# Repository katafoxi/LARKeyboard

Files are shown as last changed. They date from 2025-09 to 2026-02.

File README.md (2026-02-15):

# LARKeyboard

Кастомная механическая клавиатура с открытым исходным кодом и интегрированным трекболом.

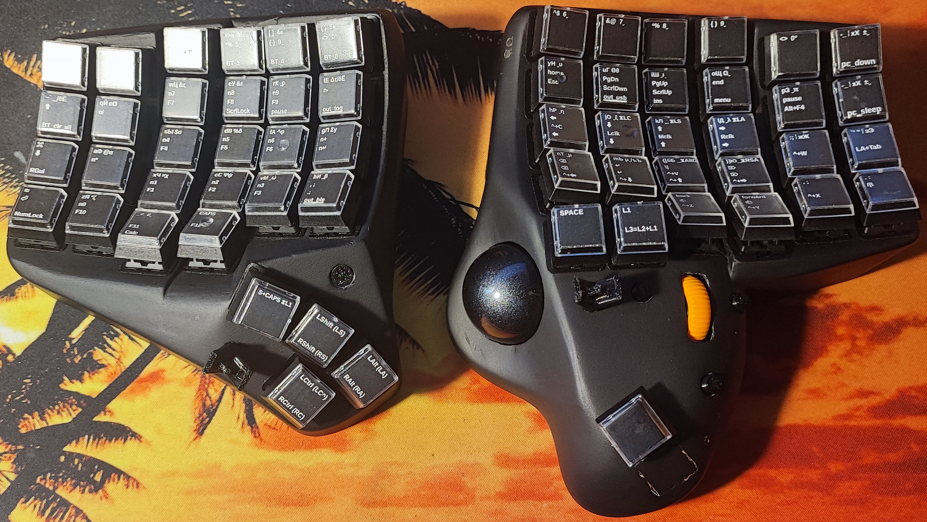
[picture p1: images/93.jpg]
LARKeyboard — вид спереди
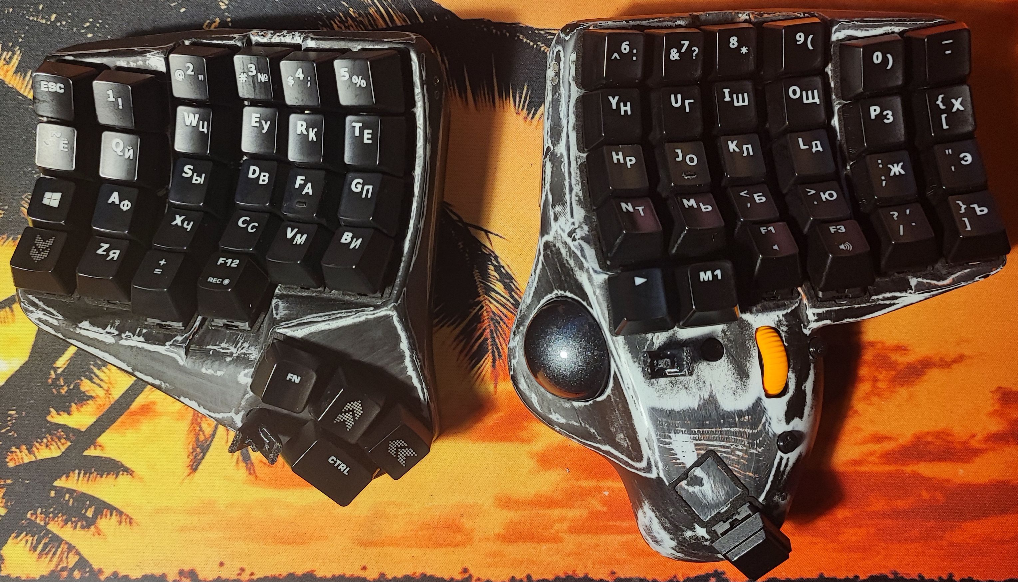
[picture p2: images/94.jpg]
LARKeyboard — вид сбоку
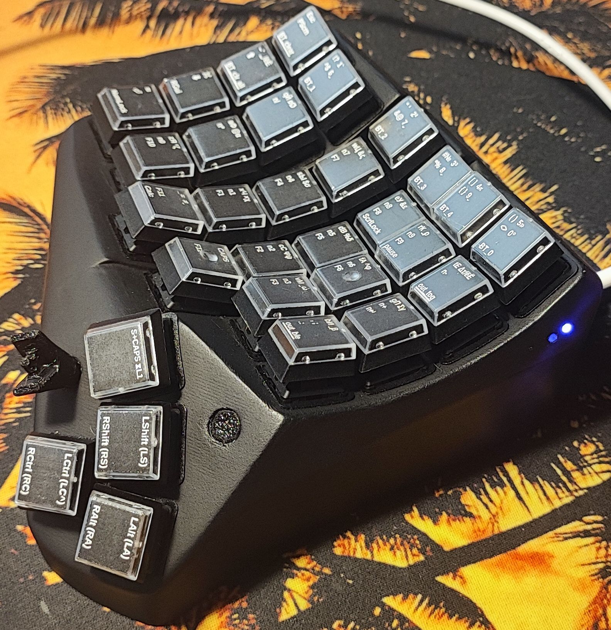
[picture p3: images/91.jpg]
LARKeyboard — трекбол и thumb cluster
  

---

## 📑 Содержание

- [Характеристики](#характеристики)
- [Быстрые ссылки](#-быстрые-ссылки)
- [Hardware](#-hardware) — BOM, инструменты, модели, этапы сборки
- [Дополнительная информация](#-дополнительная-информация) — прошивка и ссылки

---

## Характеристики  
- **Прошивка:** ZMK 
- **Макет:** Split Dactyl Manuform
- **Микроконтроллер:** (NRF52840 Development Board )  
- **Кейкапы:** ( MX )  
- **Интерфейс:** (USB-C, Bluetooth)  
- **Особенности:** 
  - длительное время автономной работы, благодаря 4 акумуляторам формата AA и возможности использования донгла
  - интегрированный серийный трекбол ProtoArc EM04 Wireless, функционирующий независимо от клавиатуры
  - 9 клавиш на thumbcluster
  - сборка без плат
  - подходит для больших и маленьких рук

## 🔗 Быстрые ссылки
- [Большая статья](https://habr.com/ru/articles/946684/)

- 📁 [Репозиторий с прошивкой](https://github.com/katafoxi/zmk-keyboard-lark)

- 📊 [Легенды клавиш и кеймап](https://docs.google.com/spreadsheets/d/1xXg7V_umpOhjsuPLZJ3ickMg2kA1LSvM3Gqmz-Sg8EQ/edit)

## 🛠️ Hardware
<details>
<summary>📦 Bill of Materials (BOM) (кликните, чтобы развернуть)</summary>

| Этап сборки | Компонент | Количество |
| --- | :--- | ---: |
| 3D-печать | Филамент для 3D-печати | 700 гр |
| Печать деталей левой половины | [_left_print.stp](hardware/_left_print.stp) | 1 шт |
| Печать деталей правой половины | [_right_print.stp](hardware/_right_print.stp) | 1 шт |
| Удаление поддержек | | |
| Установка заглушек | Заглушка в гнездо под покраску | 60 шт |
| Ошкуривание | | |
| Покраска | Грунтовка + Эмаль | 1+1 баллон |
| Удаление заглушек | | |
| Установка вплавляемых втулок | Втулка вплавляемая М3х5 | 24 шт |
| Установка Hotswap коннекторов | Коннектор Hotswap MX | 59 шт |
| Пайка столбцов | Проволока красная медная эмалированная  QA-1/155R 2UEW ø0.2мм | 500 м |
| Пайка рядов из диодов | Диод  1N4148 | 59 шт |
| Пайка и установка nice!nano_v2 | Плата NRF52840 | 3 шт |
| Обжим проводов для батарейного отсека | Отсек батарейный UM-3x2 | 2 шт |
| Установка аккумуляторов | Аккумулятор 14500 АА Ni-Mh | 4 шт |
| Установка движкового переключателя | Переключатель движковый L-KLS7-SS03-12D02-EG03 | 2 шт |
| Установка тактильной кнопки | Кнопка тактильная SWT-20-5 | 3 шт |
| Установка 5-позиционной кнопки | Кнопка DIP 5 Five way Switch Multi-direction | 2 шт |
| Установка наклеек под свитчи | Наклейки шумоизолирующие | 59 шт |
| Установка свитчей | Свитч Cherry MX | 59 шт |
| Установка трекбола | Трекбол ProtoArc EM04 Wireless | 1 шт |
| Установка O-rings | Keyboard o-rings 8x5x1.5mm | 59 шт |
| Установка кейкапов | Кейкапы | 59 шт |
| Установка крышек | Винт с потайной головкой М3х6 | 24 шт |
| Установка держателя L-ключа | Ключ 2-1-Х9 ГОСТ Р 57981-2017 | 1 шт |
| Установка магнитов для L-ключа | Магнитик неодимовый | 2 шт |
| Сборка и пайка донгла | | 1 шт |

</details> 

<details>
<summary> 🔧 Необходимые инструменты </summary><div style="background-color: #f8f9fa; color: #212529; padding: 15px; border-radius: 5px; margin: 10px 0;">

- ✏️ Пинцет
- ✂️ Кусачки
- 🔪 Скальпель
- 🔌 Паяльник + Флюс
- 📏 Пилочка для ногтей
- 🔥 Зажигалка
- 🔧 Набор ключей шестигранных
- Наждачная сетка P180, P240, P600, P1000
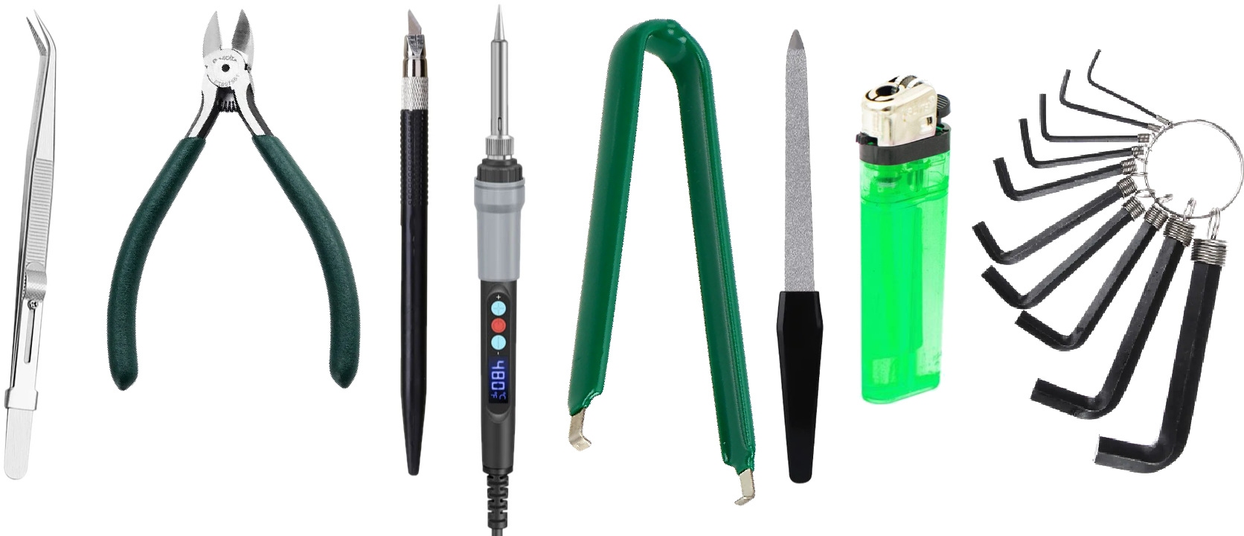
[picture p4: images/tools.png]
tools


</div> </details>

<div style="background-color: #d1e7dd; color: #0f5132; padding: 12px; border-radius: 5px; margin: 10px 0;">

**💡 Примечание:** На корпусах заглушены некоторые отверстия под покраску и аккуратное срезание после покраски.

</div>

<details> <summary>📐 Модели для печати</summary><div style="background-color: #f8f9fa; color: #212529; padding: 15px; border-radius: 5px; margin: 10px 0;">

`hardware/_left_print.stp` 
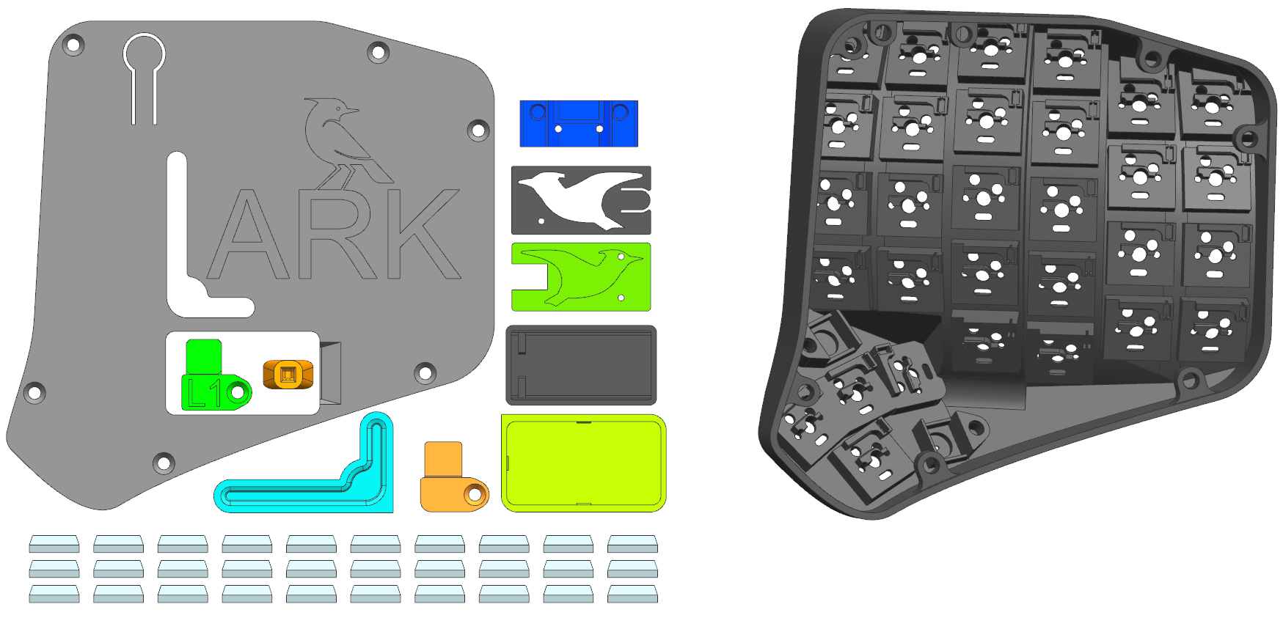
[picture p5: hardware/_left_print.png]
left_print


`hardware/_right_print.stp` 
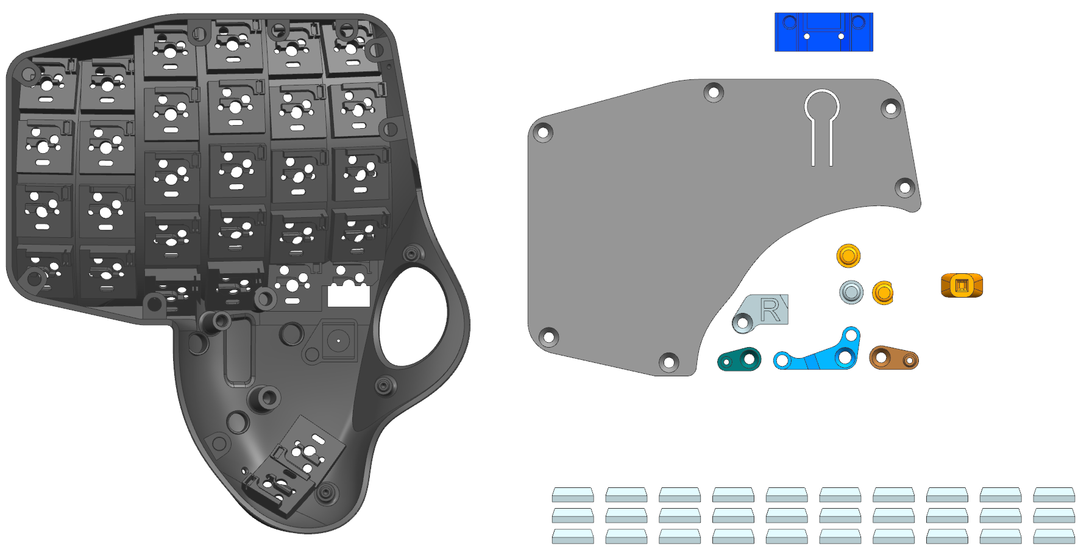
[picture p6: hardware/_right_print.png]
right_print


</div></details>

<details >
<summary>Исходная сборка </summary>

`hardware/_LARKeyboard_full_assambly.stp`
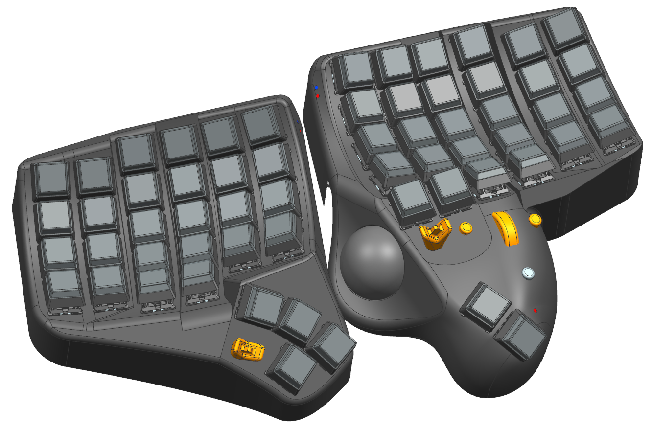
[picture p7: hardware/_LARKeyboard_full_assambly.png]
Полная сборка LARKeyboard

</details>

<details>
<summary>🎥 Видео последовательности сборки левой половинки</summary>

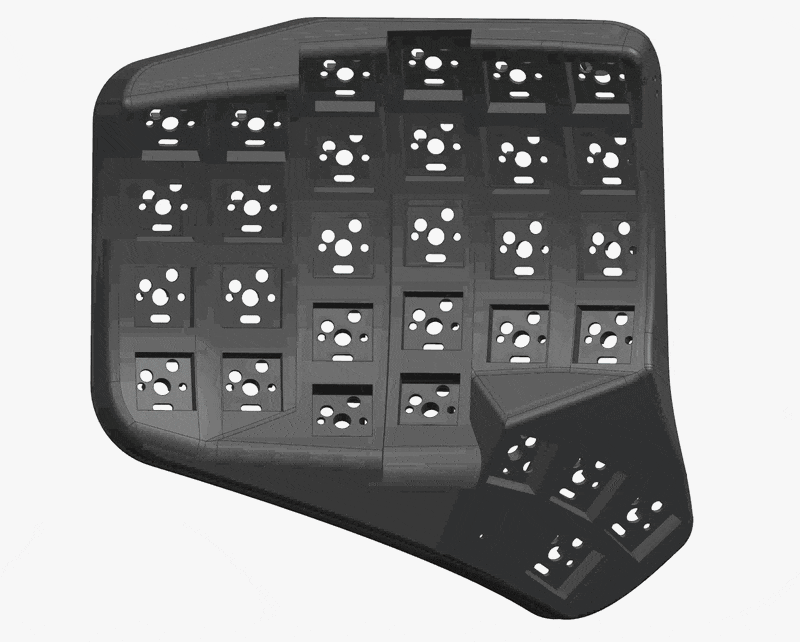
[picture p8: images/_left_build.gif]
build_left

</details>

<details>
<summary>🎥 Видео последовательности сборки правой половинки</summary>

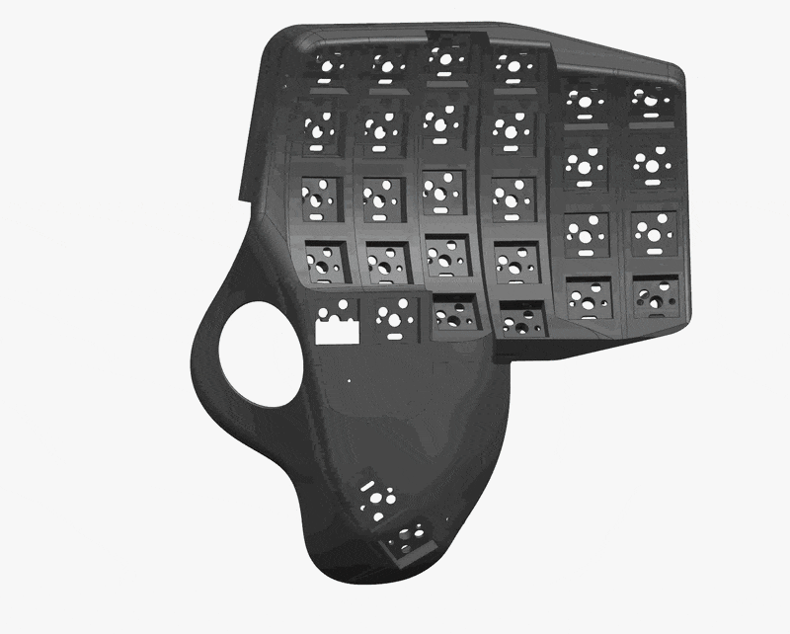
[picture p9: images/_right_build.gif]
build_right

</details>

## 📸 Фото последовательности сборки

<details>
<summary>🔄 Этап 1: Подготовка корпуса</summary>

<div style="background-color: #f8f9fa; color: #212529; padding: 15px; border-radius: 5px; margin: 10px 0;">

**Процесс:**
- Печать
- Удаление поддержек
- Установка заглушек
- Ошкуривание

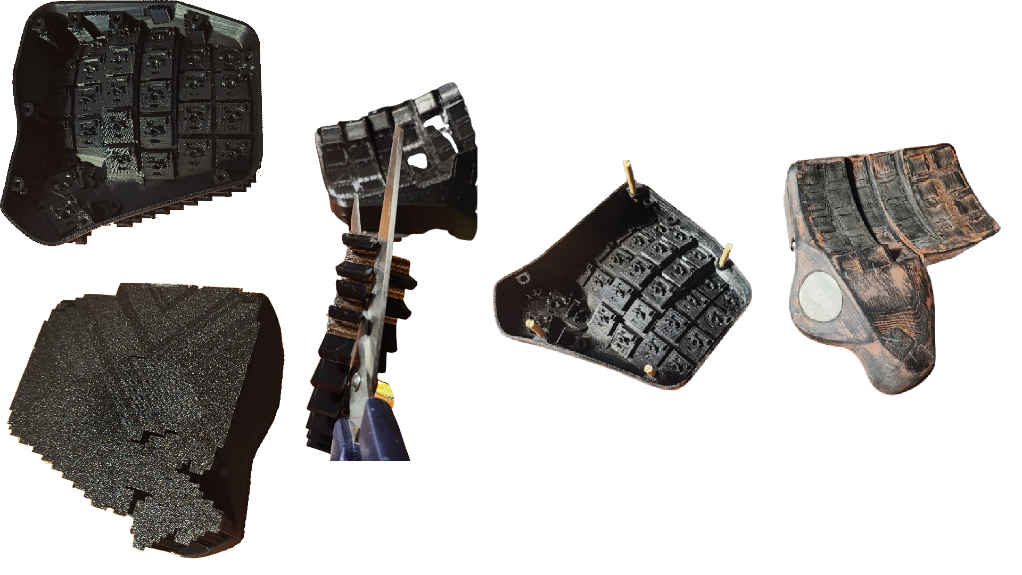
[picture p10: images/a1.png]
Этап 1


</div>
</details>

<details>
<summary>🎨 Этап 2: Покраска</summary>

<div style="background-color: #fff3cd; color: #856404; padding: 15px; border-radius: 5px; margin: 10px 0;">

**Процесс покраски:**
1. Грунтовка + Эмаль
2. Ошкуривание P800-P1000
3. Покраска (Эмаль)
4. Удаление заглушек

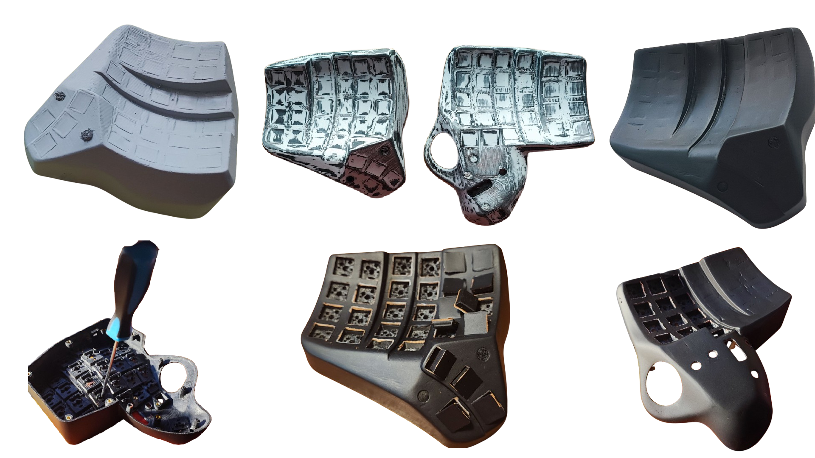
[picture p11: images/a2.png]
Этап 2


</div>
</details>

<details>
<summary>🔌 Этап 3: Электроника</summary>

<div style="background-color: #f8f9fa; color: #212529; padding: 15px; border-radius: 5px; margin: 10px 0;">

**Процесс:**
- Установка hotswap
- Установка вплавляемых втулок
- Пайка столбцов
- Пайка строк
- Пайка платы NRF52840
- Пайка 5-позиционного переключателя

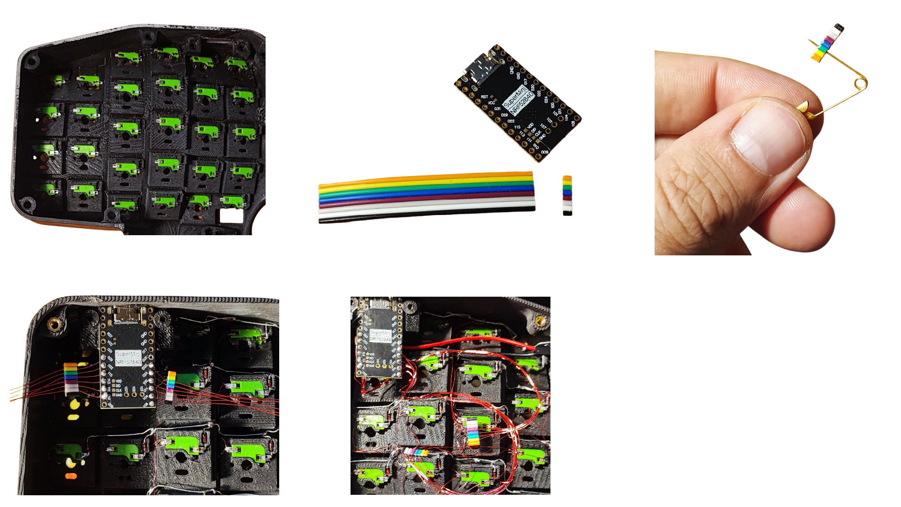
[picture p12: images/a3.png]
Этап 3


</div>
</details>

### 📊 Схемы подключения

<div style="background-color: #cff4fc; color: #055160; padding: 12px; border-radius: 5px; margin: 10px 0;">

**Схема левой половинки** 
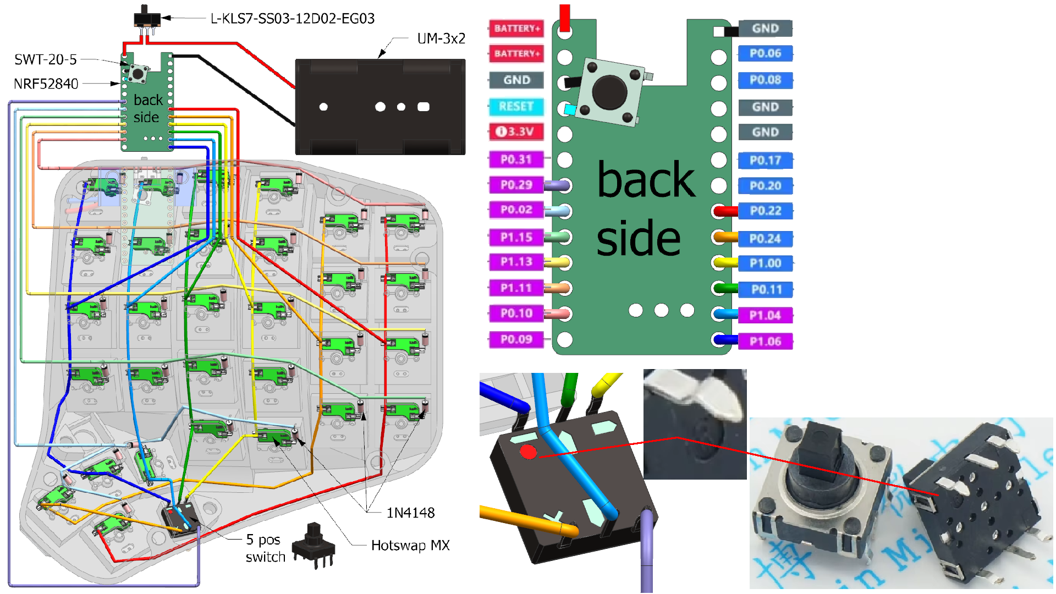
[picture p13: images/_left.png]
left


**Схема правой половинки**
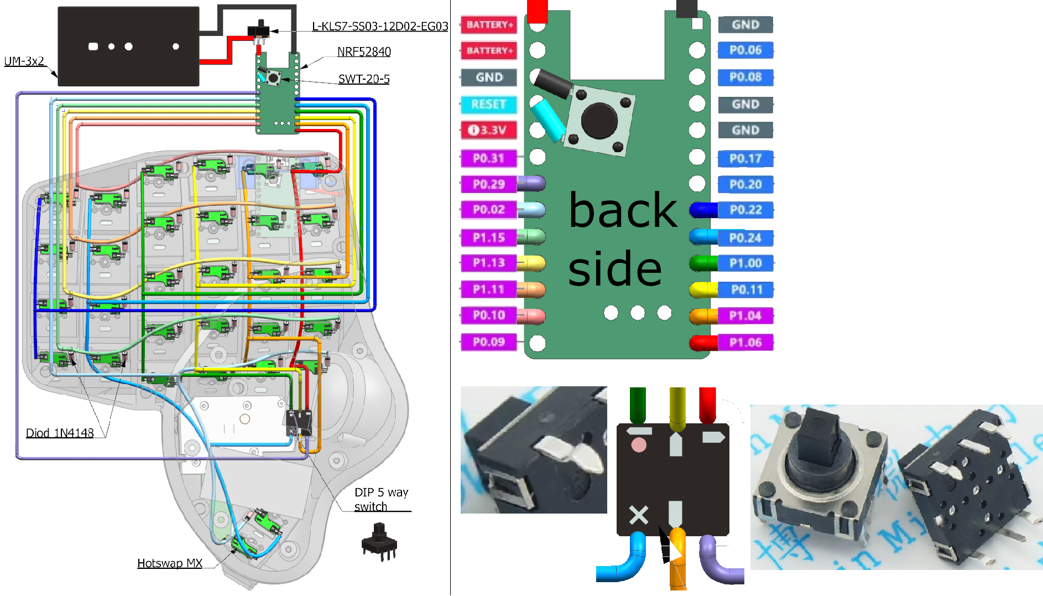
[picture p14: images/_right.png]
right


</div>

<details>
<summary>💡 Этап 4: Световоды и трекбол</summary>

<div style="background-color: #f8f9fa; color: #212529; padding: 15px; border-radius: 5px; margin: 10px 0;">

<div style="background-color: #d4edda; color: #155724; padding: 12px; border-radius: 5px; margin: 10px 0;">

**💡 Совет по световодам:**
В качестве световода можно использовать прозрачный PLA/PETG ø1.75мм или оптоволокно. 
Отрезаем 2 кусочка длиной 10 см, изгибаем под 90°, вставляем в отверстия в корпусе, 
потом вставляем в держатель платы, наживляем крепеж, обрезаем лишнее, шлифуем торцы пилочкой для ногтей.

</div>

**Процесс:**
- Установка светопроводов
- Установка Платы NRF52840
- Подрезка детали платы трекбола
- Установка платы трекбола
- Установка трекбола

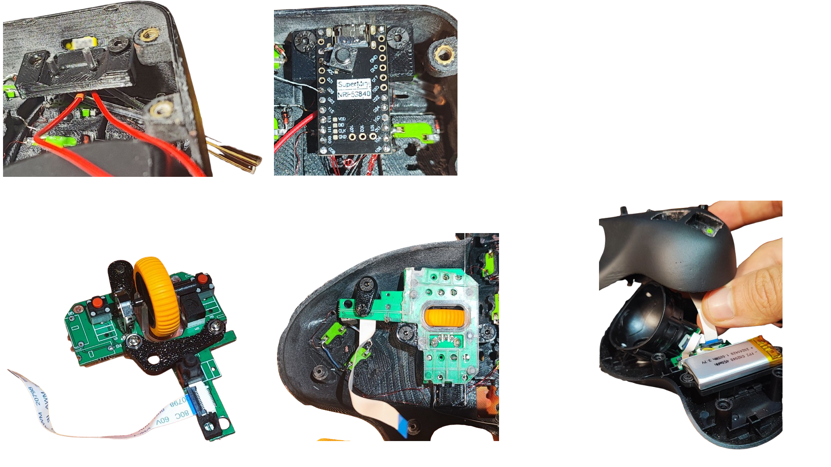
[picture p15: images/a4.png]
Этап 4


<div style="background-color: #fff3cd; color: #856404; padding: 12px; border-radius: 5px; margin: 10px 0;">

**⚠️ Важно:** Отверстие под шар специально сделано меньше. Острым ножом срезая пластик, 
добейтесь геометрии, при которой шар не выпадает, но легко извлекается для очистки.

</div>

</div>
</details>

<details>
<summary>🔋 Этап 5: Финальная сборка</summary>

<div style="background-color: #f8f9fa; color: #212529; padding: 15px; border-radius: 5px; margin: 10px 0;">

**Процесс:**
- Обжим держателя батареек (мама)
- Установка держателя батареек (суперклей)
- Сборка крышек
- Сборка донгла
- Установка шумоизолирующих наклеек

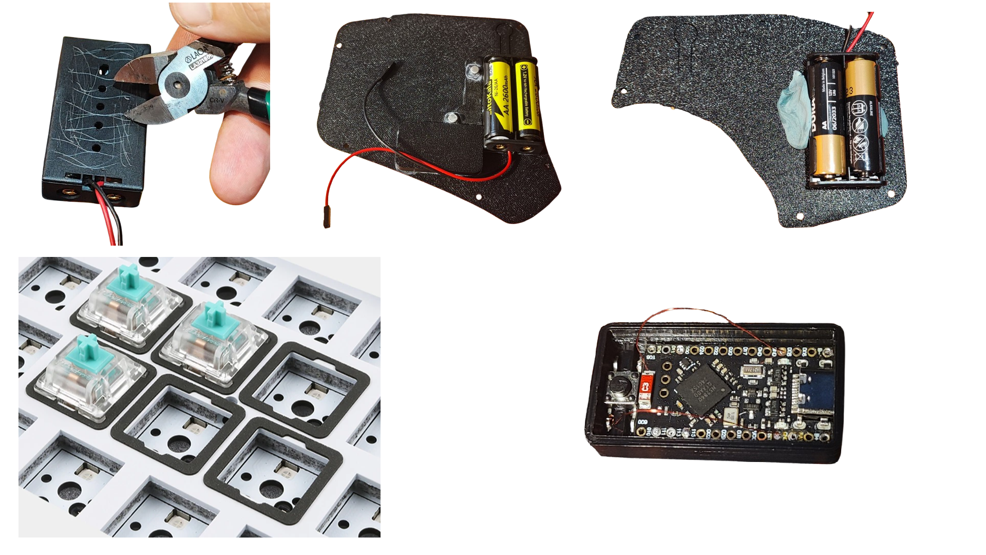
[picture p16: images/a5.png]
Этап 5


<div style="background-color: #d4edda; color: #155724; padding: 12px; border-radius: 5px; margin: 10px 0;">

**💡 Инструкция:** Обжать провода (выводы B+ и B− от платы — папа), 
соединить с выводами от держателя батареек. Установить крышки.

</div>

</div>
</details>

<details>
<summary>⌨️ Этап 6: Установка свитчей и кейкапов</summary>
<div style="background-color: #f8f9fa; color: #212529; padding: 15px; border-radius: 5px; margin: 10px 0;">

При использовании сборных колпачков с прозрачной крышкой:
1. Распечатать [легенды](https://docs.google.com/spreadsheets/d/1xXg7V_umpOhjsuPLZJ3ickMg2kA1LSvM3Gqmz-Sg8EQ/edit)
2. Нарезать легенды
3. Собрать колпачки

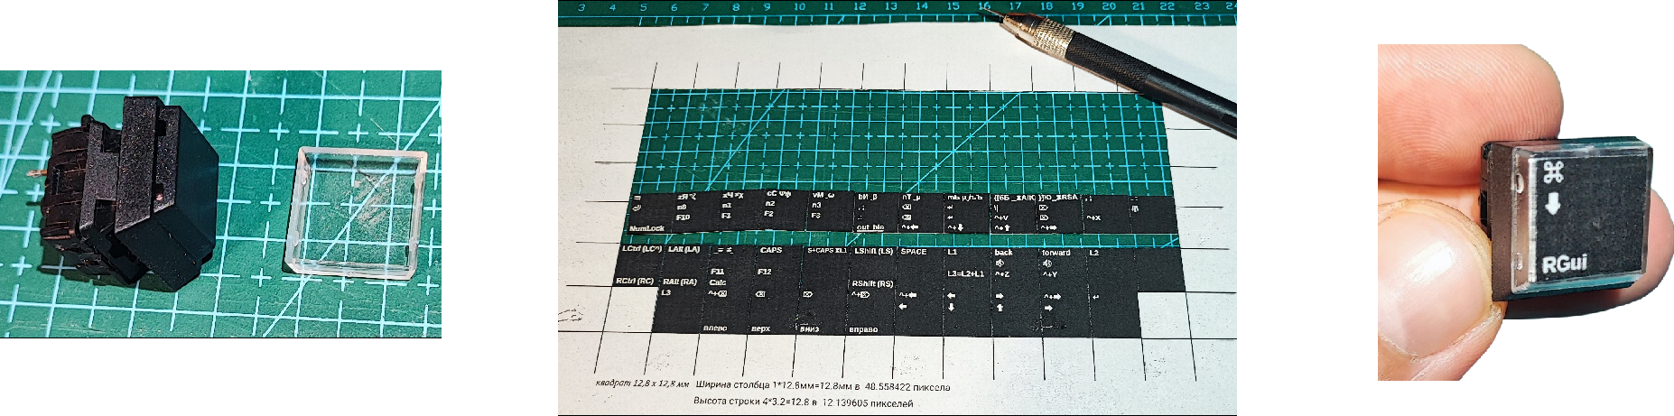
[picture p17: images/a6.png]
Установка клавиш

</div></details>

---

## 📚 Дополнительная информация

### ⌨️ Прошивка (Firmware)

Процесс прошивки стандартный для ZMK:

1. [Официальная инструкция ZMK](https://zmk.dev/docs/user-setup#installing-the-firmware) — установка и настройка
2. [Репозиторий прошивки LARKeyboard](https://github.com/katafoxi/zmk-keyboard-lark) — клонировать, собрать и прошить

### 🔗 Полезные ссылки

| Ресурс | Ссылка |
|---|---|
| 📁 Прошивка | [zmk-keyboard-lark](https://github.com/katafoxi/zmk-keyboard-lark) |
| 📊 Легенды и кеймап | [Google Таблицы](https://docs.google.com/spreadsheets/d/1xXg7V_umpOhjsuPLZJ3ickMg2kA1LSvM3Gqmz-Sg8EQ/edit) |
| 📄 Статья на Habr | [Большая статья о сборке](https://habr.com/ru/articles/946684/) |

---

<div style="background-color: #d4edda; color: #155724; padding: 15px; border-radius: 5px; margin: 10px 0; text-align: center;">

**🎉 Поздравляем с завершением сборки LARKeyboard!**  
Наслаждайтесь использованием вашей кастомной клавиатуры с трекболом!

</div>

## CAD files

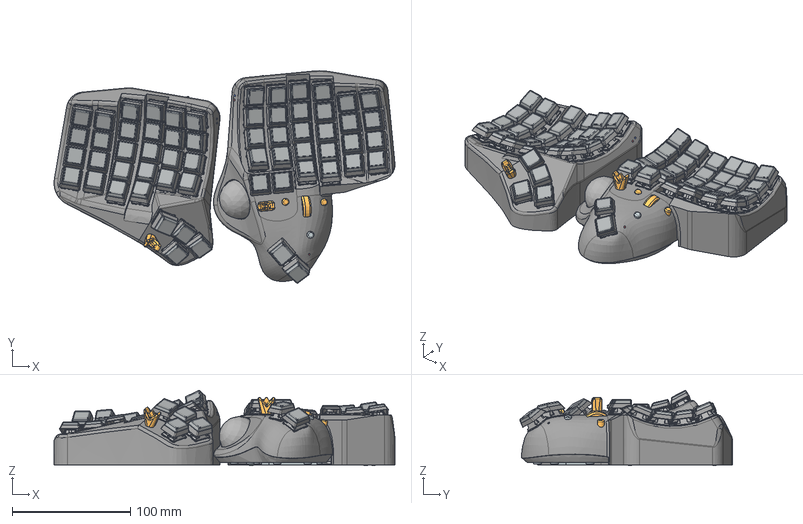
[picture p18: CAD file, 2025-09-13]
hardware/_LARKeyboard_full_assambly.stp
288.9 x 180.0 x 63.6 mm
socket_plug x 60
cap_crown x 2
l_lightway
l_nicenano_mount x 2
nicenano-v2 x 3
switch_TS6-THT_H-4.3 x 3
switch_KLS7-SS03-12D02 x 2
l_switchs
Screw_ISO_10642_M3x6 x 22
diode_capslock
Nut insert M3x5x5 x 23
l_5_1_mount
cap_2layer x 60
switch_CherryMX x 60
diod 1N4148 x 60
hotswap_Kailh x 60
switch_5-WayTactileButton10mmTHT x 2
l_cover_dongle_holder
AA_battery_holder x 2
AA_battery x 4
lark_dongle_MODEL_SOLIDS
dongle_case
dongle_logo
dongle_cover
l_cover_plate
l_hexkey_holder
Ключ 2-1-Х9 ГОСТ Р 57981-2017
l_case
r_pcb_strip_3
r_ProtoArc_pcb_MODEL_WF
r_ProtoArc_pcb_MODEL_SOLIDS
switch_Kailh_6x6x7.3_MI627301D07 x 2
r_lightway
r_pcb_strip_2
r_pcb_strip_1
r_5_1_mount
r_click_r
r_click_resolution
r_click_l
r_cover
r_case
r_ProtoArc_base

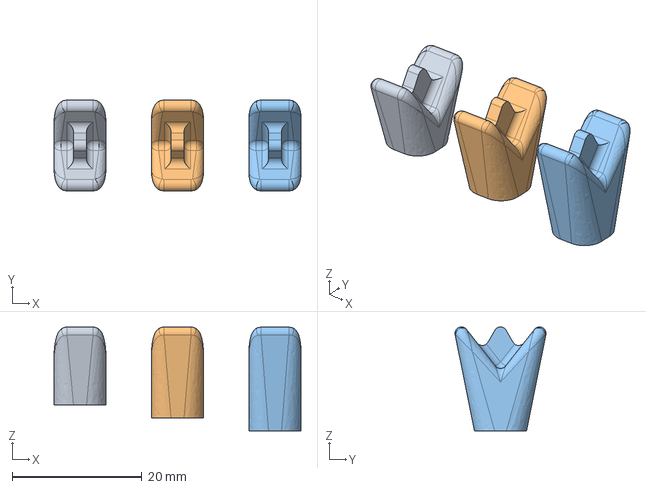
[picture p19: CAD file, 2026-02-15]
hardware/cap_crown_3versions.stp
38.0 x 14.0 x 16.0 mm

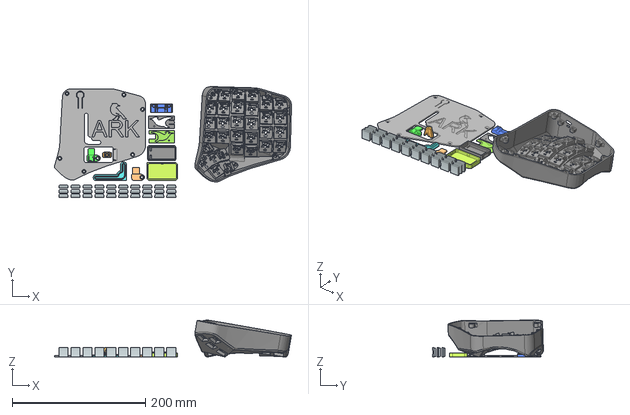
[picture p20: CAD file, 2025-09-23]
hardware/_left_print.stp
355.9 x 166.5 x 55.5 mm

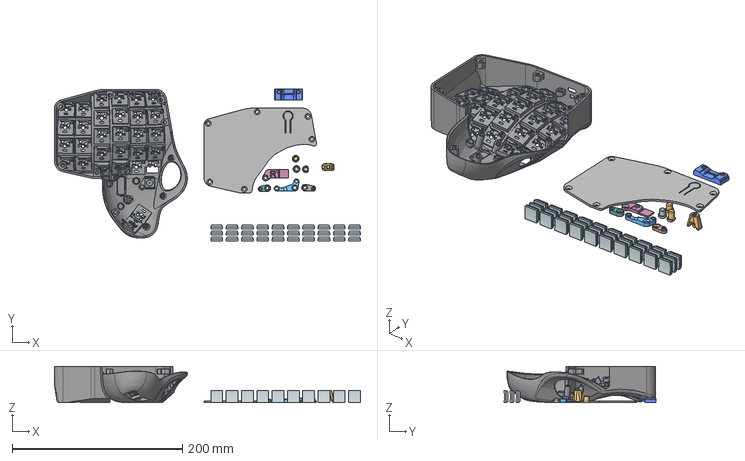
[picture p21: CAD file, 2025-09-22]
hardware/_right_print.stp
359.8 x 178.5 x 42.5 mm

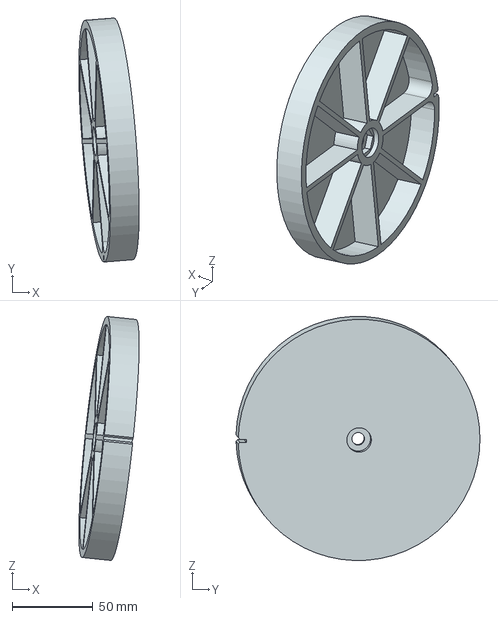
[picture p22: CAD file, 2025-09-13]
hardware/tool_sander.stp
37.3 x 151.1 x 151.1 mm

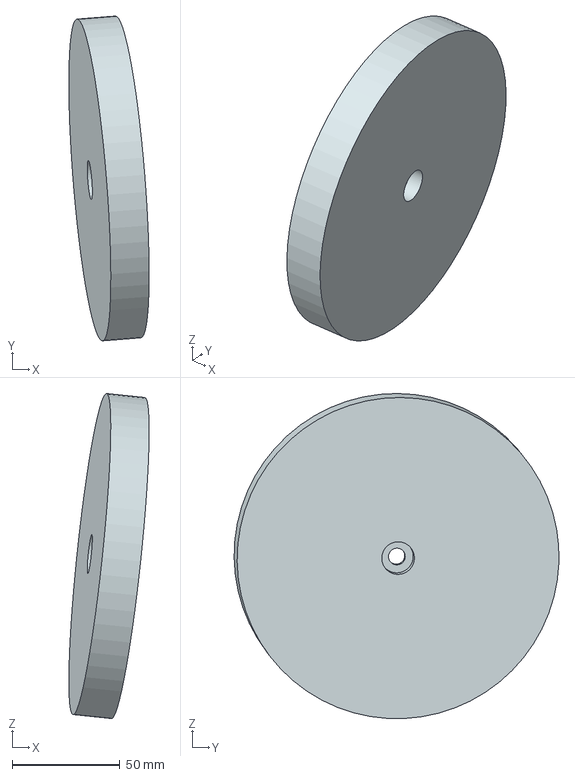
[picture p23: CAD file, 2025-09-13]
hardware/tool2_sander.stp
37.4 x 151.0 x 151.1 mm

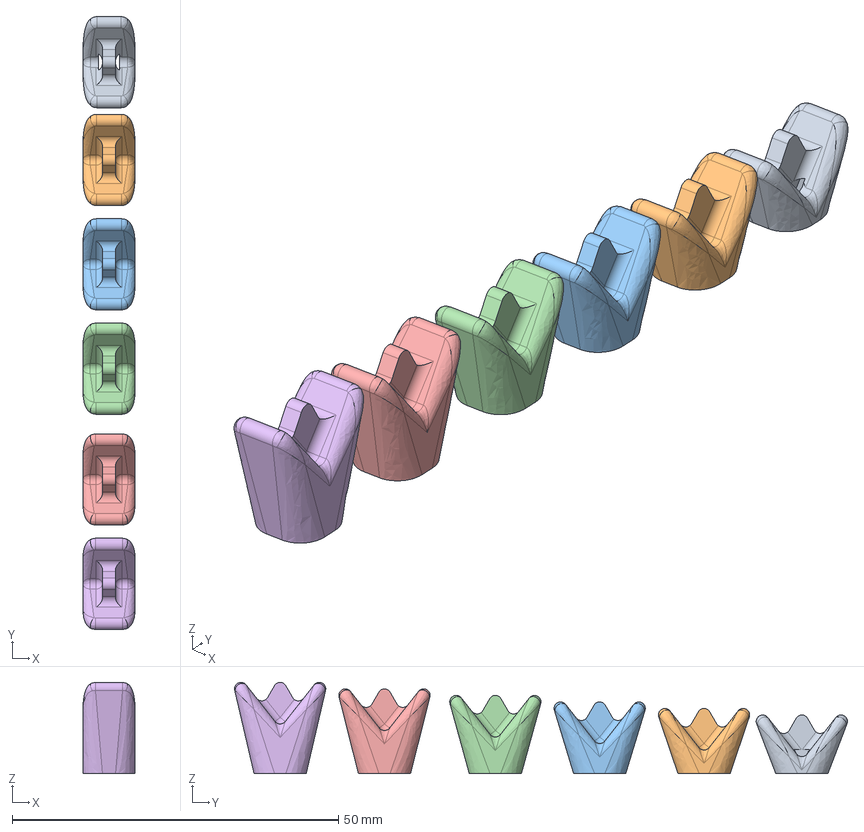
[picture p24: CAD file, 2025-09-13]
hardware/cap_crown_9-14mm.stp
8.00 x 94.0 x 14.0 mm

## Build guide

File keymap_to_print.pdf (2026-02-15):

Esc | !? 1` | " ' 2² #№ 3³ [ ] 4« | ( ) 5» | ^$ 6ˬ | &@ 7ˬ | *% 8ˬ | { } 9ˬ | <> 0°
PScrn | ^$ 6ˬ | &@ 7ˬ | *% 8ˬ | { } 9ˬ | <> 0°
~` ˬˬ/ёЁ qЙ øØ | wЦ &ς | eУ &ε | rК ˬρ | tЕ Δτ/ёЁ yН ˬυ | uГ Θθ | iШ ˬι | oЩ Ωˬ | pЗ ˬπ
⬆ | n/ | n7 | n8 | n9 | n- | home | PgDn | PgUp | end | pause
F7 | F8 | F9 | Esc | ScrlDwn ScrlUp | Alt+F4
ScrlLock pause | ins | menu
⌘ | aФ @α | sЫ $σ | dВ %δ | fА ^φ | gП Σγ | hР ˬη | jО ˬξ ⧗LC kЛ ˬˬ ⧗LS lД ˬλ ⧗LA :; ⦙ жЖ `' " ⦙ эЭ
⬇ | n* | n4 | n5 | n6 | n+ | ⬅ | ⬇ | ⬆ | ➡
F4 | F5 | F6 | n↵ | ^+C | Lclk | Mclk | Rclk | ^+W | LA+Tab
RGui | | | | | | ⬅ | ⬇ | ⬆ | ➡
⭾ | zЯ °ζ | xЧ ×χ | cС Ψψ | vМ ˬω | bИ ˬβ | nТ ˬμ | , ; | . :
⏎ | n0 | n1 | n2 | n3 | , ; | ⌫ | ↵ | \| | ⌦ | /|\
| F10 | F1 | F2 | F3 | .: | ⌫ | ↵ | ^+V | ⌦ | ^+X
| | | | | | ^+⬅ | ^+⬇ | ^+⬆ | ^+➡
_= ≠ˬ | CAPS | SPACE | L1 | back | forward L2
| | | | | | | | 🔉 | 🔊
| | F11 | F12 | | | | | ^+Z | ^+Y
| | Calc
| L3 | ^+⌫ | ⌫ | ⌦ | ^+⌦ | ^+⬅ | ⬅ | ➡ | ^+➡ | ↵
| | | | | | ⬅ | ⬇ | ⬆ | ➡
| | влево | верх | вниз | вправо
| | | | S+CAPS

-_ ⦙ хХ ±ˬ

pc_down
-_ ⦙ хХ ±ˬ

pc_sleep

mЬ μˬ/ъЪ

NumLock
LAlt (LA)

RAlt (RA)

}]Юˬˬ⧗RSA

GAMEMOD
LCtrl (LC^) | LShift (LS)

L3=L2+L1
RCtrl (RC) | RShift (RS)

{[бБ ˬˬ⧗AltGr

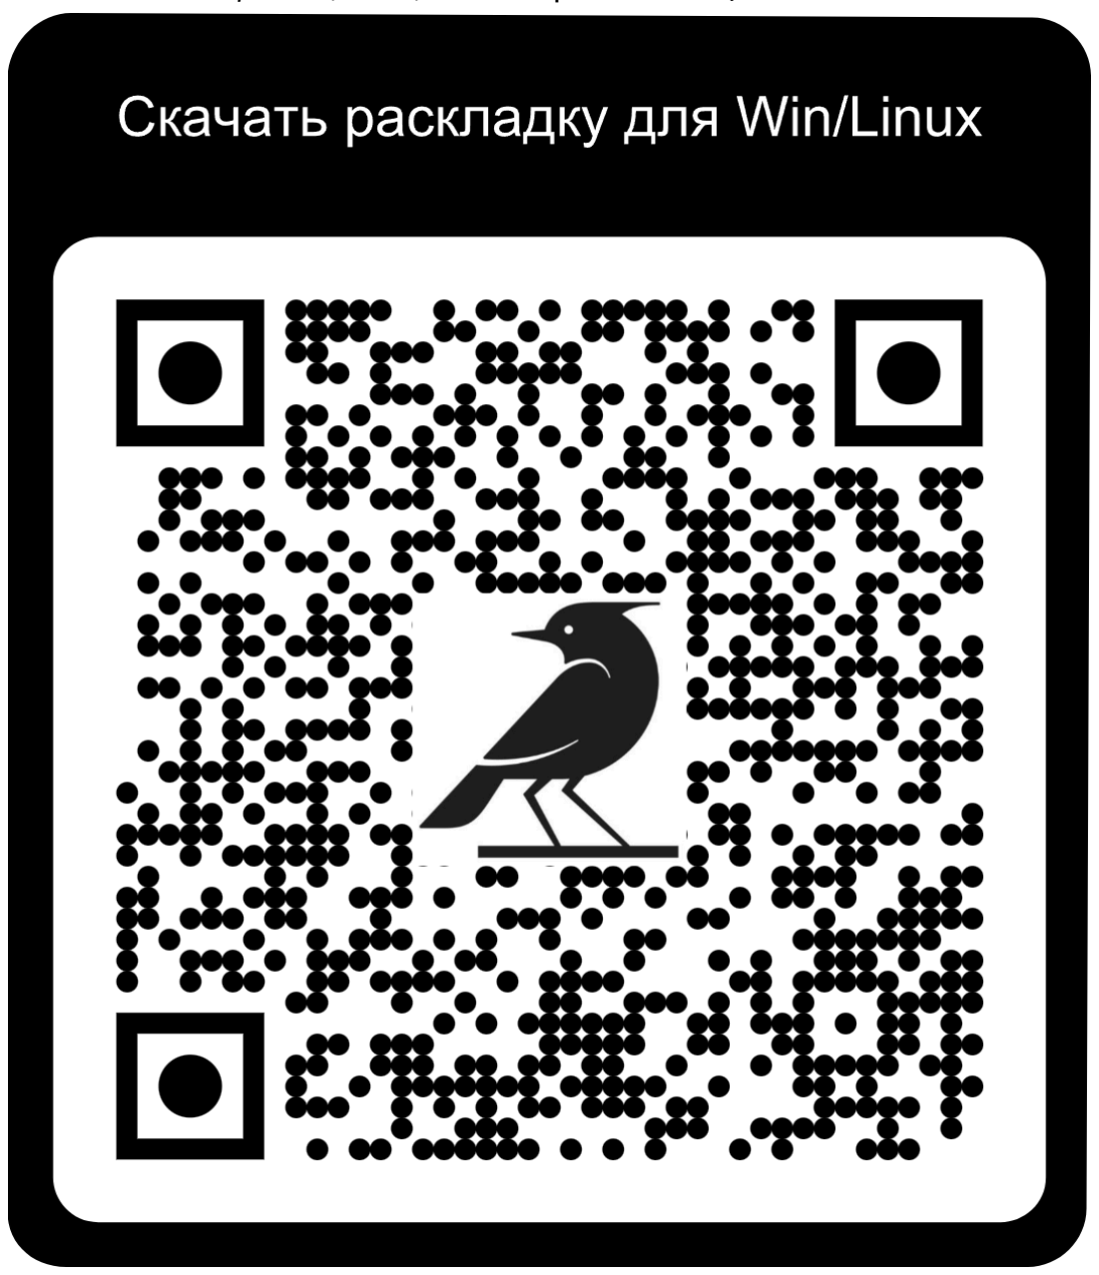
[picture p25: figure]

квадрат 12,8 х 12,8 мм Ширина столбца 1*12.8мм=12.8мм в 48.558422 пиксела | Высота строки 4*3.2=12.8 в 12.139605 пикселей

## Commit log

2025-06-17 add BOM
2025-06-17 add l_case.stp
    [l_case.stp]
2025-06-17 add left details
    [l_5pos_switch_mount.stp, l_cover.stp, l_hexkey_holder.stp]
2025-06-17 rm примечания
2025-06-18 add some 3d models details
    [l_led_mount.stp, l_nicenano_mount.stp, r_5pos_switch_mount.stp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]
2025-09-17 fix _right_print
    [_right_print.stp]
2025-09-22 fix _right_print.stp
    [_right_print.stp]
2025-09-23 fix left cover model
    [_left_print.stp]
2026-02-15 Add keymap printout PDF for reference
2026-02-15 Add new STEP file for cap crown with multiple versions and detailed geometric representations
    [cap_crown_3versions.stp]
2026-02-15 Add hardware print file to .gitignore
